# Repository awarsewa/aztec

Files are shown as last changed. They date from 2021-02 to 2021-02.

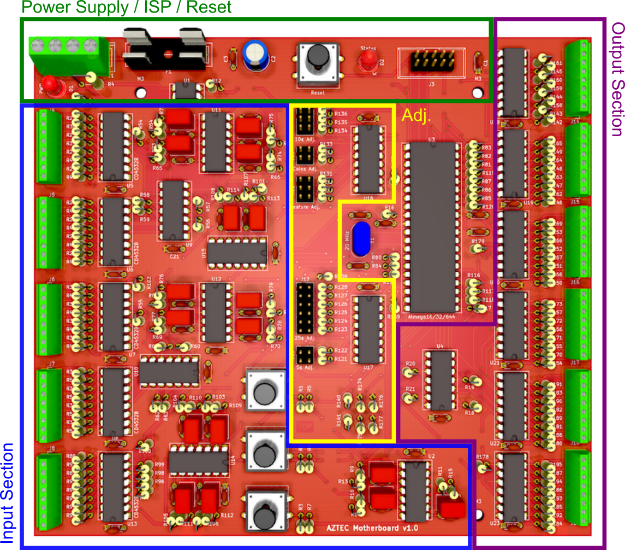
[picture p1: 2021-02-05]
docs/images/aztec_pcb_rendering.png

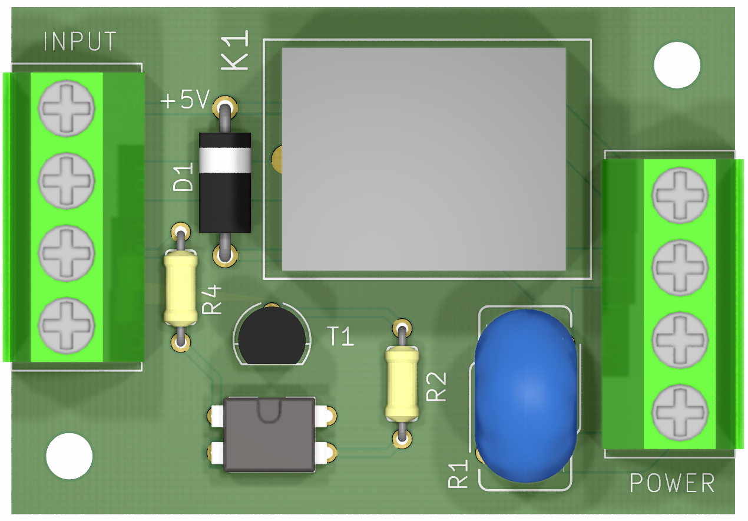
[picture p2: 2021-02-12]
docs/images/relay_pcb.png

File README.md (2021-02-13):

# aztec
Bringing a 1976 pinball machine back to life.

[:corn: Wiki](https://github.com/awarsewa/aztec/wiki)

### The machine
Aztec is a Williams® pinball machine for 4 players. Check it out on the [Internet Pinball Machine Database](https://www.ipdb.org/machine.cgi?gid=119). There is also a [solid state version](https://www.ipdb.org/machine.cgi?gid=4828) of the same machine. Mine is from the electromechanical series -- and this is where the fun starts. Of course it wasn't functional. The entire cabinet had been completely gutted, with only a few tilt mechanisms left dangling about. However, the playfield and the backbox were still mostly intact. Repairing it seemed tough, but since it's cool to have your own pinball machine, I decided to give it a shot.

### The project
It would have been rather expensive and difficult to get original spare parts for, or replicas of, all the missing components. So why not replace aztec's brain with a microcontroller? The looks and feel of the machine would still be the same. Only what's under the hood would be slightly more modern. Maybe this is a sacrilege for real pinball lovers... I have a feeling it is. Like an inverse Frankenstein - pretty on the outside. But I already did it, so there's no way back and no repentance. If you want to know how I've done it, check out the [:corn: repository wiki](https://github.com/awarsewa/aztec/wiki).

### What's in this repository?
The source code running on the microcontroller and the PCB schematics. Basically everything you need to do something similar. 

### Getting involved
In case you have questions or suggestions, need support or simply want to get in touch, feel free to [send me a message](mailto:alexander.warsewa@posteo.net?subject=[Aztec]).

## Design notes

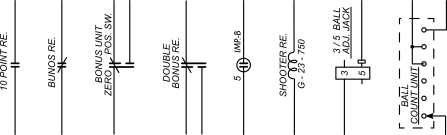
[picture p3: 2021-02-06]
docs/images/schematic_symbols.png

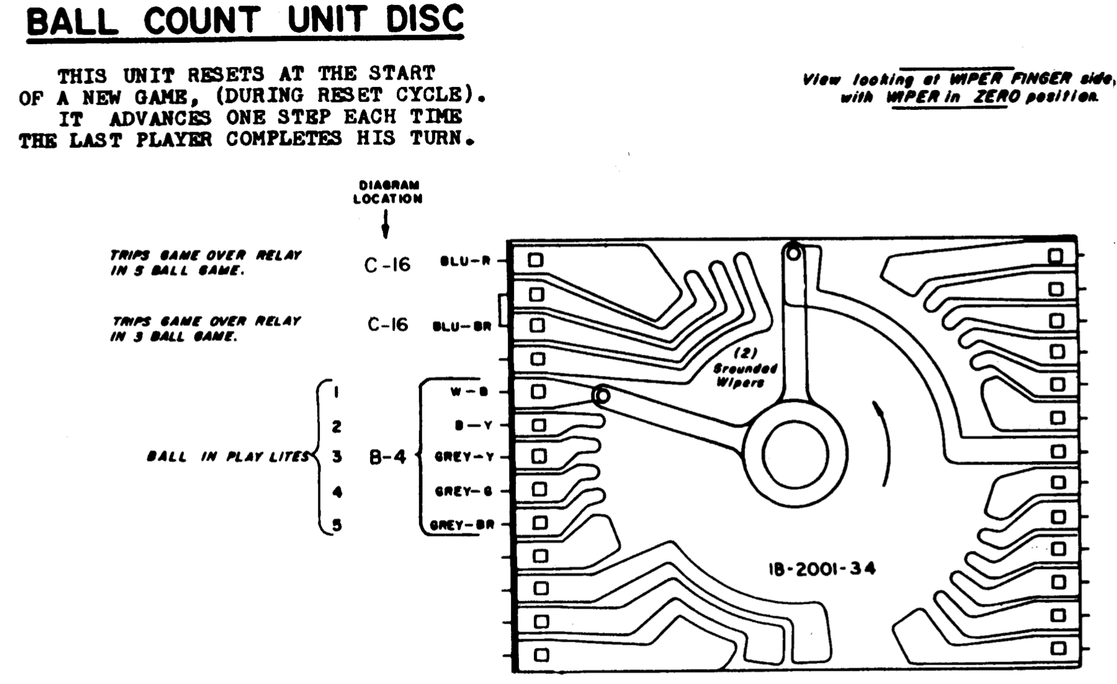
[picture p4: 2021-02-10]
docs/images/ball_count_unit.png

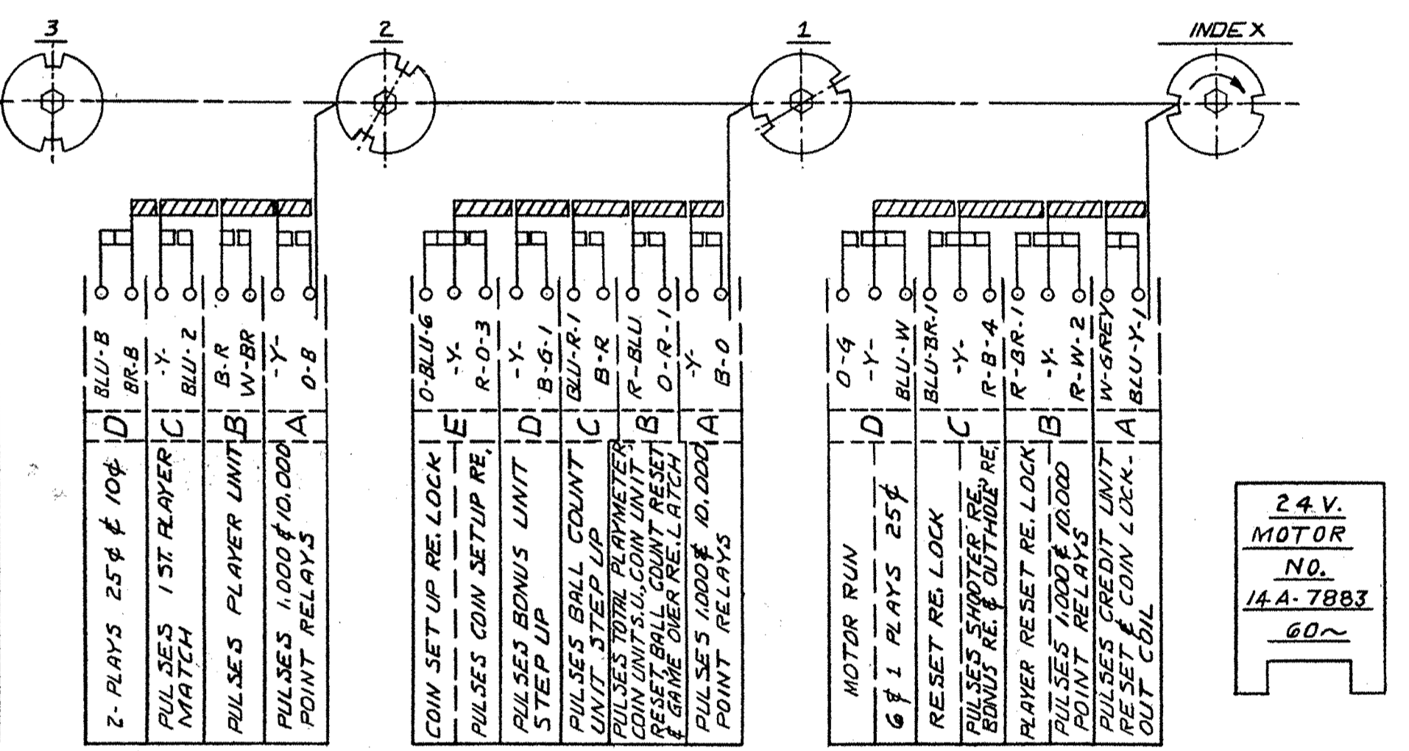
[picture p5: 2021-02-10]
docs/images/score_motor.png

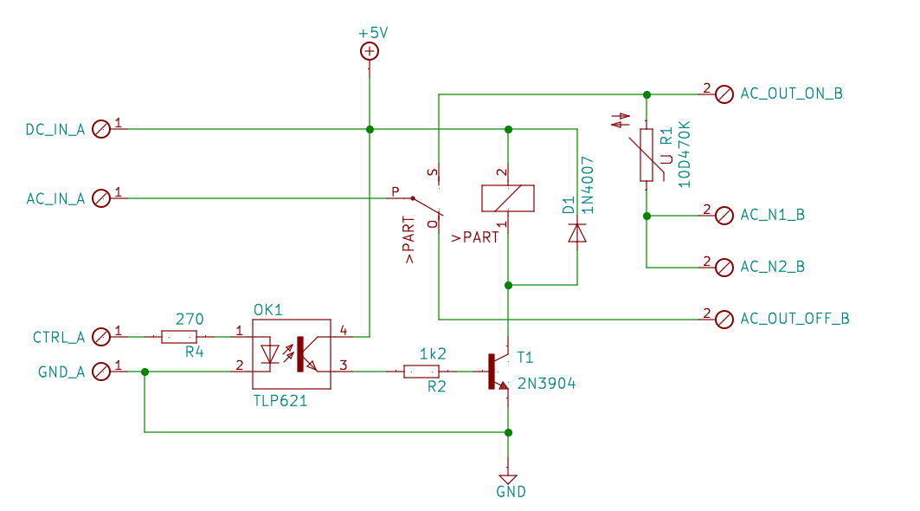
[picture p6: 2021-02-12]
docs/images/relay_sch.png

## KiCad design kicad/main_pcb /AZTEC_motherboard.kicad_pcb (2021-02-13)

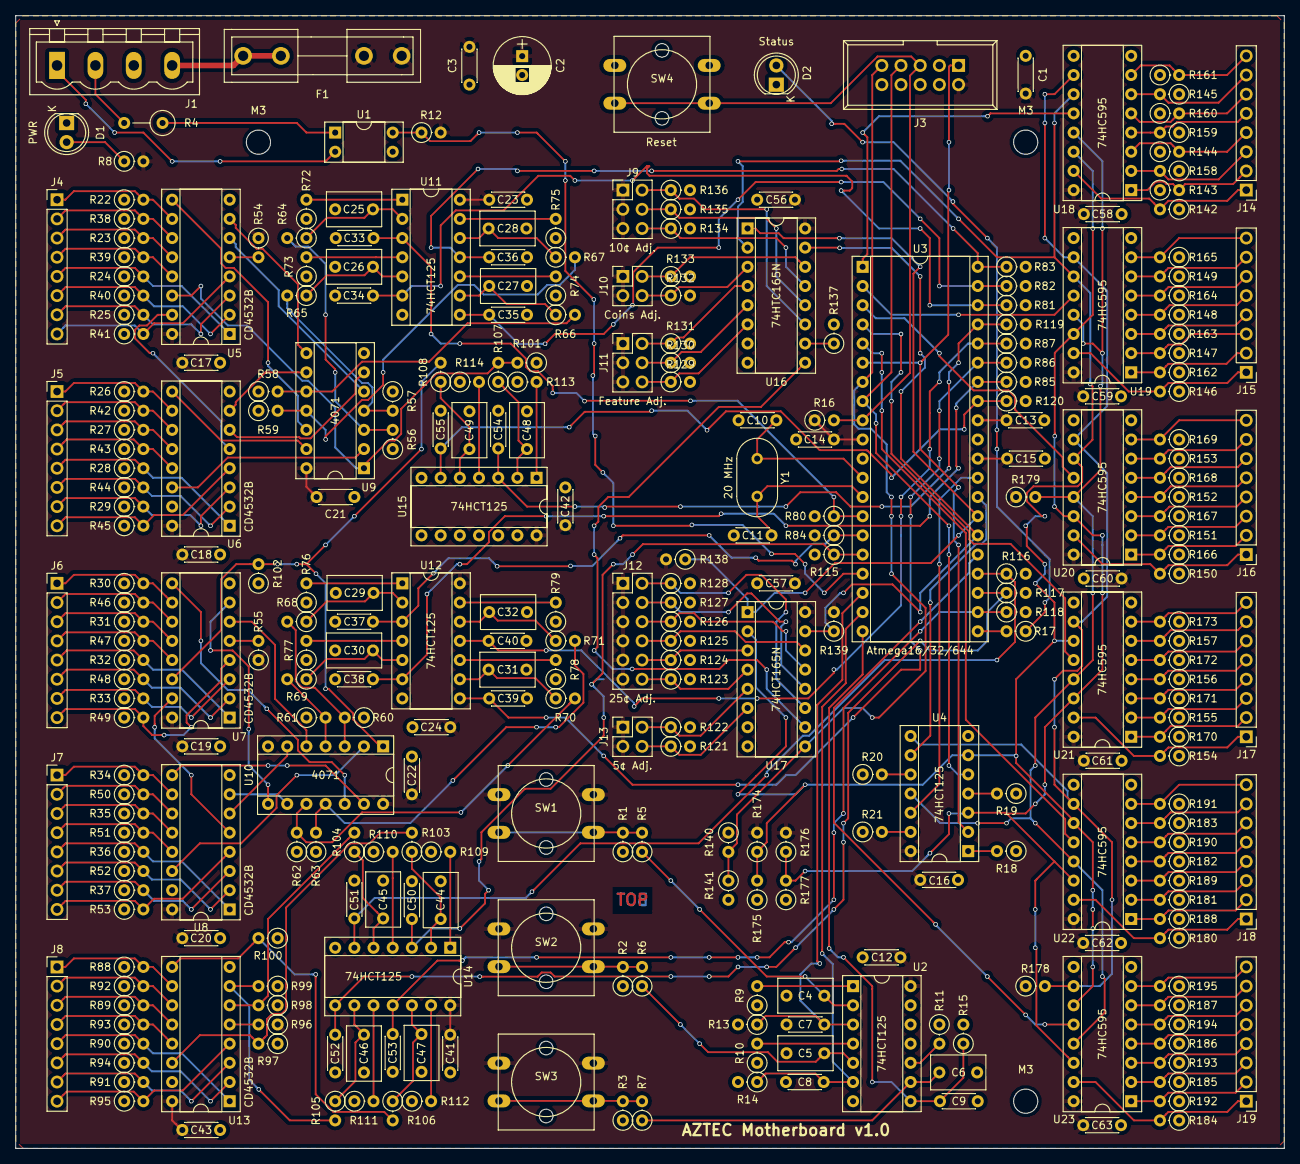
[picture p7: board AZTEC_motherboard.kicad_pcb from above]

Board: 2 copper layers, 168.0 x 150.0 mm, 310 parts (0 on the bottom side), 227 nets.

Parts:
C1, C3, C7, C8, C9, C12, C13, C14, C15, C16, C17, C18, C19, C20, C21, C22, C23, C24, C33, C34, C35, C36, C37, C38, C39, C40, C41, C42, C43, C50, C51, C52, C53, C54, C55, C56, C57, C58, C59, C60, C61, C62, C63: 100n; C_Disc_D4.3mm_W1.9mm_P5.00mm
C2: 1u; CP_Radial_D7.5mm_P2.50mm
C4, C5, C6, C25, C26, C27, C28, C29, C30, C31, C32, C44, C45, C46, C47, C48, C49: 1µ; C_Rect_L7.2mm_W4.5mm_P5.00mm_FKS2_FKP2_MKS2_MKP2
C10, C11: 22p; C_Disc_D4.3mm_W1.9mm_P5.00mm
D1: PWR; LED-5MM
D2: STATUS; LED-5MM
F1: Fuse; Fuseholder5x20_horiz_open_inline_Type-I
J1: Conn_01x04_Female; PhoenixContact_MSTBVA-G_04x5.08mm_Vertical
J3: ISP; IDC_Header_Straight_10pins
J4: Inputs_1; Pin_Header_Straight_1x08_Pitch2.54mm
J5: Inputs_2; Pin_Header_Straight_1x08_Pitch2.54mm
J6: Inputs_3; Pin_Header_Straight_1x08_Pitch2.54mm
J7: Inputs_4; Pin_Header_Straight_1x08_Pitch2.54mm
J8: Inputs_5; Pin_Header_Straight_1x08_Pitch2.54mm
J9: 10¢ Adjust; Pin_Header_Straight_2x03_Pitch2.54mm
J10: 2 coins - 3 plays; Pin_Header_Straight_2x02_Pitch2.54mm
J11: Feature Adjust; Pin_Header_Straight_2x03_Pitch2.54mm
J12: 25¢ Adjust; Pin_Header_Straight_2x06_Pitch2.54mm
J13: 5¢ Adjust; Pin_Header_Straight_2x02_Pitch2.54mm
J14: Outputs_1; Pin_Header_Straight_1x08_Pitch2.54mm
J15: Outputs_2; Pin_Header_Straight_1x08_Pitch2.54mm
J16: Outputs_3; Pin_Header_Straight_1x08_Pitch2.54mm
J17: Outputs_4; Pin_Header_Straight_1x08_Pitch2.54mm
J18: Outputs_5; Pin_Header_Straight_1x08_Pitch2.54mm
J19: Outputs_6; Pin_Header_Straight_1x08_Pitch2.54mm
M3, M3#2, M3#3: MountingHole_3.2mm_M3
R1, R2, R3, R9, R10, R11, R12, R13, R14, R15, R16, R18, R19, R20, R21, R22, R23, R24, R25, R26, R27, R28, R29, R30, R31, R32, R33, R34, R35, R36, R37, R38, R39, R40, R41, R42, R43, R44, R45, R46, R47, R48, R49, R50, R51, R52, R53, R54, R55, R56, R57, R58, R59, R60, R61, R62, R63, R72, R73, R74, R75, R76, R77, R78, R79, R80, R81, R82, R83, R84, R85, R86, R87, R88, R89, R90, R91, R92, R93, R94, R95, R96, R97, R98, R99, R100, R101, R102, R109, R110, R111, R112, R113, R114, R115, R116, R117, R118, R119, R120, R121, R122, R123, R124, R125, R126, R127, R128, R129, R130, R131, R132, R133, R134, R135, R136, R137, R138, R139, R140, R141, R142, R143, R144, R145, R146, R147, R148, R149, R150, R151, R152, R153, R154, R155, R156, R157, R158, R159, R160, R161, R162, R163, R164, R165, R166, R167, R168, R169, R170, R171, R172, R173, R174, R175, R176, R177, R178, R179, R180, R181, R182, R183, R184, R185, R186, R187, R188, R189, R190, R191, R192, R193, R194, R195: 10k; R_Axial_DIN0207_L6.3mm_D2.5mm_P2.54mm_Vertical
R4: 2k2; R_Axial_DIN0309_L9.0mm_D3.2mm_P5.08mm_Vertical
R5, R6, R7, R64, R65, R66, R67, R68, R69, R70, R71, R103, R104, R105, R106, R107, R108: 22k; R_Axial_DIN0207_L6.3mm_D2.5mm_P2.54mm_Vertical
R8, R17: 100R; R_Axial_DIN0207_L6.3mm_D2.5mm_P2.54mm_Vertical
SW1, SW2, SW3, SW4: Reset; SW_PUSH-AZTEC
U1: SFH620A; DIP-4_W7.62mm_Socket
U2, U4, U11, U12, U14, U15: 74HCT125; DIP-14_W7.62mm_Socket
U3: ATMEGA16/32/644; DIP-40_W15.24mm_Socket
U5, U6, U7, U8, U13: CD4532B; DIP-16_W7.62mm_Socket
U9, U10: 4071; DIP-14_W7.62mm_Socket
U16, U17: 74HCT165N; DIP-16_W7.62mm_Socket
U18, U19, U20, U21, U22, U23: 74HC595; DIP-16_W7.62mm_Socket
Y1: 20 MHz; Resonator-2pin_w10.0mm_h5.0mm

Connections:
/AC_zero_crossing: R12.1, U1.4, U3.17
/Adjusts/CP: R174.1, R175.2, U4.6, U16.2, U17.2, U18.11, U19.11, U20.11, U21.11, U22.11, U23.11
/Adjusts/~CE: R139.1, U3.26, U16.15, U17.15
/Adjusts/~PL: R138.1, U3.27, U16.1, U17.1
/Button1: C7.2, R13.1, U2.3, U3.18
/Button2: C8.2, R14.1, U2.6, U3.19
/Button3: C9.2, R15.1, U2.8, U3.20
/Inputs/GS1: C33.2, R80.1, U3.14, U11.3
/Inputs/GS2: C37.2, R84.1, U3.15, U12.3
/Inputs/GS3: C50.2, R115.1, U3.16, U14.3
/Inputs/Q10: C36.2, R83.1, U3.40, U11.11
/Inputs/Q11: C35.2, R82.1, U3.39, U11.8
/Inputs/Q12: C34.2, R81.1, U3.38, U11.6
/Inputs/Q13: C54.2, R119.1, U3.37, U15.3
/Inputs/Q20: C40.2, R87.1, U3.36, U12.11
/Inputs/Q21: C39.2, R86.1, U3.35, U12.8
/Inputs/Q22: C38.2, R85.1, U3.34, U12.6
/Inputs/Q23: C55.2, R120.1, U3.33, U15.6
/Inputs/Q30: C53.2, R118.1, U3.22, U14.11
/Inputs/Q31: C52.2, R117.1, U3.23, U14.8
/Inputs/Q32: C51.2, R116.1, U3.24, U14.6
/MISO: J3.9, R140.2, R141.1, U3.7, U17.9
/MOSI: J3.1, U3.6, U4.2
/Outputs/MOSI_buf: R176.1, R177.2, U4.3, U18.14, U19.14, U20.14, U21.14, U22.14, U23.14
/Outputs/RCK1: U3.1, U18.12
/Outputs/RCK2: U3.2, U19.12
/Outputs/RCK3: U3.3, U20.12
/Outputs/RCK4: U3.4, U21.12
/Outputs/RCK5: U3.5, U22.12
/Outputs/RCK6: U3.25, U23.12
/Outputs/~OE_buf: R179.2, U4.11, U18.13, U19.13, U20.13, U21.13, U22.13, U23.13
/Outputs/~SCL_buf: R178.2, U4.8, U18.10, U19.10, U20.10, U21.10, U22.10, U23.10
/SCK: J3.7, U3.8, U4.5
/~OE: U3.29, U4.12
/~RESET: J3.5, R16.2, SW4.2, SW4.4, U3.9
/~SCL: U3.28, U4.9
GND: C1.1, C2.2, C3.1, C4.1, C5.1, C6.1, C7.1, C8.1, C9.1, C10.2, C11.2, C12.2, C13.1, C14.1, C15.2, C16.2, C17.1, C18.1, C19.1, C20.1, C21.1, C22.1, C23.2, C24.2, C25.1, C26.1, C27.1, C28.1, C29.1, C30.1, C31.1, C32.1, C33.1, C34.1, C35.1, C36.1, C37.1, C38.1, C39.1, C40.1, C41.2, C42.2, C43.1, C44.1, C45.1, C46.1, C47.1, C48.1, C49.1, C50.1, C51.1, C52.1, C53.1, C54.1, C55.1, C56.1, C57.1, C58.2, C59.2, C60.2, C61.2, C62.2, C63.2, D1.1, D2.1, J1.3, J3.4, J3.6, J3.8, J3.10, R1.1, R2.1, R3.1, R9.1, R10.1, R11.1, R13.2, R14.2, R15.2, R18.1, R19.1, R20.1, R21.1, R22.1, R23.1, R24.1, R25.1, R26.1, R27.1, R28.1, R29.1, R30.1, R31.1, R32.1, R33.1, R34.1, R35.1, R36.1, R37.1, R38.1, R39.1, R40.1, R41.1, R42.1, R43.1, R44.1, R45.1, R46.1, R47.1, R48.1, R49.1, R50.1, R51.1, R52.1, R53.1, R56.1, R57.1, R58.1, R59.1, R60.1, R61.1, R62.1, R63.1, R72.1, R73.1, R74.1, R75.1, R76.1, R77.1, R78.1, R79.1, R80.2, R81.2, R82.2, R83.2, R84.2, R85.2, R86.2, R87.2, R88.1, R89.1, R90.1, R91.1, R92.1, R93.1, R94.1, R95.1, R97.1, R98.1, R99.1, R100.1, R101.1, R102.1, R109.1, R110.1, R111.1, R112.1, R113.1, R114.1, R115.2, R116.2, R117.2, R118.2, R119.2, R120.2, R121.2, R122.2, R123.2, R124.2, R125.2, R126.2, R127.2, R128.2, R129.2, R130.2, R131.2, R132.2, R133.2, R134.2, R135.2, R136.2, R137.2, R141.2, R142.1, R143.1, R144.1, R145.1, R146.1, R147.1, R148.1, R149.1, R150.1, R151.1, R152.1, R153.1, R154.1, R155.1, R156.1, R157.1, R158.1, R159.1, R160.1, R161.1, R162.1, R163.1, R164.1, R165.1, R166.1, R167.1, R168.1, R169.1, R170.1, R171.1, R172.1, R173.1, R175.1, R177.1, R180.1, R181.1, R182.1, R183.1, R184.1, R185.1, R186.1, R187.1, R188.1, R189.1, R190.1, R191.1, R192.1, R193.1, R194.1, R195.1, SW4.1, SW4.3, U1.3, U2.7, U3.11, U3.31, U4.7, U5.8, U6.8, U7.8, U8.8, U9.7, U10.7, U11.7, U12.7, U13.8, U14.7, U15.7, U16.8, U17.8, U18.8, U19.8, U20.8, U21.8, U22.8, U23.8
unnamed: C4.2, R5.1, U2.2
unnamed: C5.2, R6.1, U2.5
unnamed: C6.2, R7.1, U2.9
unnamed: C10.1, U3.12, Y1.1
unnamed: C11.1, U3.13, Y1.2
unnamed: C25.2, R64.1, U11.2
unnamed: C26.2, R65.1, U11.5
unnamed: C27.2, R66.1, U11.9
unnamed: C28.2, R67.1, U11.12
unnamed: C29.2, R68.1, U12.2
unnamed: C30.2, R69.1, U12.5
unnamed: C31.2, R70.1, U12.9
unnamed: C32.2, R71.1, U12.12
unnamed: C44.2, R103.1, U14.2
unnamed: C45.2, R104.1, U14.5
unnamed: C46.2, R105.1, U14.9
unnamed: C47.2, R106.1, U14.12
unnamed: C48.2, R107.1, U15.2
unnamed: C49.2, R108.1, U15.5
unnamed: D1.2, R8.1
unnamed: D2.2, R17.1
unnamed: F1.2, J1.4
unnamed: J1.1, U1.2
unnamed: J1.2, R4.2
unnamed: J4.1, R22.2, U5.10
unnamed: J4.2, R38.2, U5.11
unnamed: J4.3, R23.2, U5.12
unnamed: J4.4, R39.2, U5.13
unnamed: J4.5, R24.2, U5.1
unnamed: J4.6, R40.2, U5.2
unnamed: J4.7, R25.2, U5.3
unnamed: J4.8, R41.2, U5.4
unnamed: J5.1, R26.2, U6.10
unnamed: J5.2, R42.2, U6.11
unnamed: J5.3, R27.2, U6.12
unnamed: J5.4, R43.2, U6.13
unnamed: J5.5, R28.2, U6.1
unnamed: J5.6, R44.2, U6.2
unnamed: J5.7, R29.2, U6.3
unnamed: J5.8, R45.2, U6.4
unnamed: J6.1, R30.2, U7.10
unnamed: J6.2, R46.2, U7.11
unnamed: J6.3, R31.2, U7.12
unnamed: J6.4, R47.2, U7.13
unnamed: J6.5, R32.2, U7.1
unnamed: J6.6, R48.2, U7.2
unnamed: J6.7, R33.2, U7.3
unnamed: J6.8, R49.2, U7.4
unnamed: J7.1, R34.2, U8.10
unnamed: J7.2, R50.2, U8.11
unnamed: J7.3, R35.2, U8.12
unnamed: J7.4, R51.2, U8.13
unnamed: J7.5, R36.2, U8.1
unnamed: J7.6, R52.2, U8.2
unnamed: J7.7, R37.2, U8.3
unnamed: J7.8, R53.2, U8.4
unnamed: J8.1, R88.2, U13.10
unnamed: J8.2, R92.2, U13.11
unnamed: J8.3, R89.2, U13.12
unnamed: J8.4, R93.2, U13.13
unnamed: J8.5, R90.2, U13.1
unnamed: J8.6, R94.2, U13.2
unnamed: J8.7, R91.2, U13.3
unnamed: J8.8, R95.2, U13.4
unnamed: J9.2, R136.1, U16.11
unnamed: J9.4, R135.1, U16.12
unnamed: J9.6, R134.1, U16.13
unnamed: J10.2, R133.1, U16.14
unnamed: J10.4, R132.1, U16.3
unnamed: J11.2, R131.1, U16.4
unnamed: J11.4, R130.1, U16.5
unnamed: J11.6, R129.1, U16.6
unnamed: J12.2, R128.1, U17.11
unnamed: J12.4, R127.1, U17.12
unnamed: J12.6, R126.1, U17.13
unnamed: J12.8, R125.1, U17.14
unnamed: J12.10, R124.1, U17.3
unnamed: J12.12, R123.1, U17.4
unnamed: J13.2, R122.1, U17.5
unnamed: J13.4, R121.1, U17.6
unnamed: J14.1, R142.2, U18.15
unnamed: J14.2, R158.2, U18.1
unnamed: J14.3, R143.2, U18.2
unnamed: J14.4, R159.2, U18.3
unnamed: J14.5, R144.2, U18.4
unnamed: J14.6, R160.2, U18.5
unnamed: J14.7, R145.2, U18.6
unnamed: J14.8, R161.2, U18.7
unnamed: J15.1, R146.2, U19.15
unnamed: J15.2, R162.2, U19.1
unnamed: J15.3, R147.2, U19.2
unnamed: J15.4, R163.2, U19.3
unnamed: J15.5, R148.2, U19.4
unnamed: J15.6, R164.2, U19.5
unnamed: J15.7, R149.2, U19.6
unnamed: J15.8, R165.2, U19.7
unnamed: J16.1, R150.2, U20.15
unnamed: J16.2, R166.2, U20.1
unnamed: J16.3, R151.2, U20.2
unnamed: J16.4, R167.2, U20.3
unnamed: J16.5, R152.2, U20.4
unnamed: J16.6, R168.2, U20.5
unnamed: J16.7, R153.2, U20.6
unnamed: J16.8, R169.2, U20.7
unnamed: J17.1, R154.2, U21.15
unnamed: J17.2, R170.2, U21.1
unnamed: J17.3, R155.2, U21.2
unnamed: J17.4, R171.2, U21.3
unnamed: J17.5, R156.2, U21.4
unnamed: J17.6, R172.2, U21.5
unnamed: J17.7, R157.2, U21.6
unnamed: J17.8, R173.2, U21.7
unnamed: J18.1, R180.2, U22.15
unnamed: J18.2, R188.2, U22.1
unnamed: J18.3, R181.2, U22.2
unnamed: J18.4, R189.2, U22.3
unnamed: J18.5, R182.2, U22.4
unnamed: J18.6, R190.2, U22.5
unnamed: J18.7, R183.2, U22.6
unnamed: J18.8, R191.2, U22.7
unnamed: J19.1, R184.2, U23.15
unnamed: J19.2, R192.2, U23.1
unnamed: J19.3, R185.2, U23.2
unnamed: J19.4, R193.2, U23.3
unnamed: J19.5, R186.2, U23.4
unnamed: J19.6, R194.2, U23.5
unnamed: J19.7, R187.2, U23.6
unnamed: J19.8, R195.2, U23.7
unnamed: R1.2, R5.2, SW1.2, SW1.4
unnamed: R2.2, R6.2, SW2.2, SW2.4
unnamed: R3.2, R7.2, SW3.2, SW3.4
unnamed: R4.1, U1.1
unnamed: R9.2, U2.1
unnamed: R10.2, U2.4
unnamed: R11.2, U2.10
unnamed: R17.2, U3.21
unnamed: R18.2, U4.1
unnamed: R19.2, U4.4
unnamed: R20.2, U4.10
unnamed: R21.2, U4.13
unnamed: R54.2, U5.5
unnamed: R55.2, U7.5
unnamed: R56.2, R64.2, U9.3
unnamed: R57.2, R65.2, U9.4
unnamed: R58.2, R66.2, U9.10
unnamed: R59.2, R67.2, U9.11
unnamed: R60.2, R68.2, U10.3
unnamed: R61.2, R69.2, U10.4
unnamed: R62.2, R70.2, U10.10
unnamed: R63.2, R71.2, U10.11
unnamed: R72.2, U11.1
unnamed: R73.2, U11.4
unnamed: R74.2, U11.10
unnamed: R75.2, U11.13
unnamed: R76.2, U12.1
unnamed: R77.2, U12.4
unnamed: R78.2, U12.10
unnamed: R79.2, U12.13
unnamed: R96.2, U13.5
unnamed: R100.2, R106.2, U13.9
unnamed: R101.2, R107.2, U5.14, U9.1
unnamed: R102.2, R108.2, U7.14, U10.1
unnamed: R97.2, R103.2, U13.14
unnamed: R98.2, R104.2, U13.6
unnamed: R99.2, R105.2, U13.7
unnamed: R109.2, U14.1
unnamed: R110.2, U14.4
unnamed: R111.2, U14.10
unnamed: R112.2, U14.13
unnamed: R113.2, U15.1
unnamed: R114.2, U15.4
unnamed: R137.1, U16.10
unnamed: U5.6, U9.5
unnamed: U5.7, U9.8
unnamed: U5.9, U9.12
unnamed: U5.15, U6.5
unnamed: U6.6, U9.6
unnamed: U6.7, U9.9
unnamed: U6.9, U9.13
unnamed: U6.14, U9.2
unnamed: U7.15, U8.5
unnamed: U8.14, U10.2
unnamed: U7.6, U10.5
unnamed: U8.6, U10.6
unnamed: U7.7, U10.8
unnamed: U8.7, U10.9
unnamed: U7.9, U10.12
unnamed: U8.9, U10.13
unnamed: U16.9, U17.10
VCC: C1.2, C2.1, C3.2, C12.1, C13.2, C14.2, C15.1, C16.1, C17.2, C18.2, C19.2, C20.2, C21.2, C22.2, C23.1, C24.1, C41.1, C42.1, C43.2, C56.2, C57.2, C58.1, C59.1, C60.1, C61.1, C62.1, C63.1, F1.1, J3.2, J9.1, J9.3, J9.5, J10.1, J10.3, J11.1, J11.3, J11.5, J12.1, J12.3, J12.5, J12.7, J12.9, J12.11, J13.1, J13.3, R8.2, R12.2, R16.1, R54.1, R55.1, R96.1, R138.2, R139.2, R140.1, R174.2, R176.2, R178.1, R179.1, SW1.1, SW1.3, SW2.1, SW2.3, SW3.1, SW3.3, U2.14, U3.10, U3.30, U3.32, U4.14, U5.16, U6.16, U7.16, U8.16, U9.14, U10.14, U11.14, U12.14, U13.16, U14.14, U15.14, U16.16, U17.16, U18.16, U19.16, U20.16, U21.16, U22.16, U23.16

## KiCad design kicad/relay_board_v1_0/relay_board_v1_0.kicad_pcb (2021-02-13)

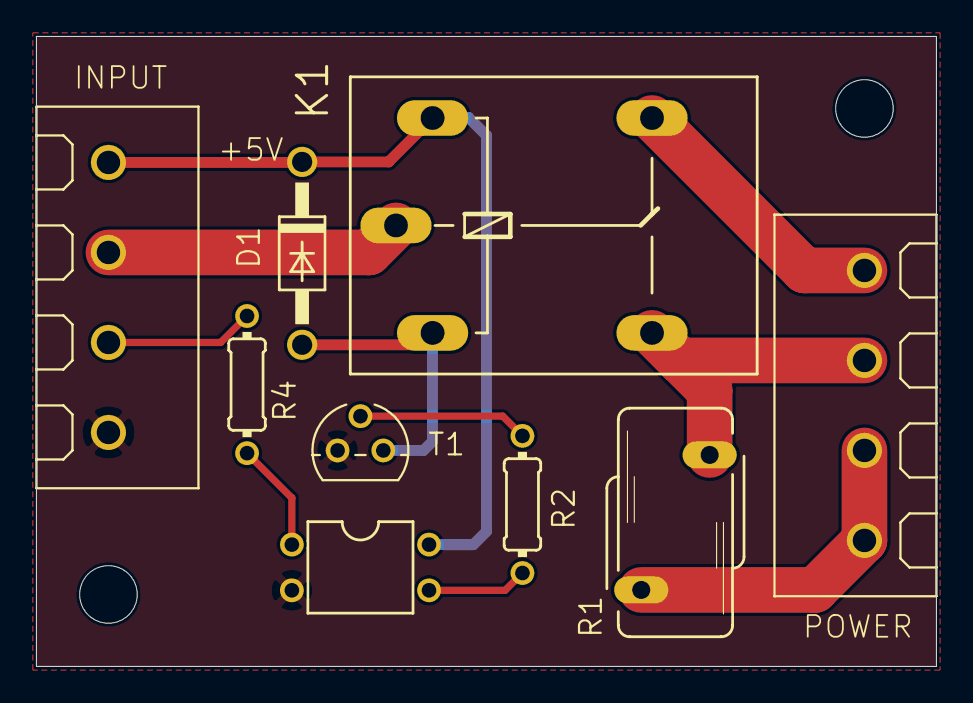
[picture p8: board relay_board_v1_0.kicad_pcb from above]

Board: 2 copper layers, 50.0 x 35.0 mm, 11 parts (0 on the bottom side), 11 nets.

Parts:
@HOLE0, @HOLE1: (no value)
D1: 1N4007; DO41-10
INPUT: OSTTA040161; 040161
K1: G5LE
OK1: TLP621; DIL04
POWER: OSTTA040161; 040161
R1: 10D470K
R2: 1k2; 0204_7
R4: 270; 0204_7
T1: 2N3904; TO92

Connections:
+5V: D1.C, INPUT.1, K1.2, OK1.4
GND: INPUT.4, OK1.2, T1.3
unnamed: D1.A, K1.1, T1.1
unnamed: INPUT.2, K1.P
unnamed: INPUT.3, R4.2
unnamed: K1.O, POWER.4
unnamed: K1.S, POWER.3, R1.2
unnamed: OK1.1, R4.1
unnamed: OK1.3, R2.2
unnamed: POWER.1, POWER.2, R1.1
unnamed: R2.1, T1.2

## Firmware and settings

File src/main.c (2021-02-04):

/* Name: main.c
 * Author: Alex
 * Copyright: 2016 by Alexander Warsewa
 * License:
 */

#include <avr/io.h>
#include <avr/wdt.h>
#include <avr/interrupt.h>
#include <util/delay.h>
#include <util/atomic.h>
#include "SPI.h"
#include "AZTEC_relays.h"
#include "score_motor.h"
#include "ball_count_unit.h"
#include "player_unit.h"
#include "credit_unit.h"
#include "coin_unit.h"
#include "bonus_unit.h"
#include "queue.h"

#define enableZeroCrossInt()    GIFR |= (1 << INTF0); GICR |= (1 << INT0)
#define disableZeroCrossInt()   GICR &= ~(1 << INT0)
#define zeroCrossIntActive()    (GICR & (1 << INT0))

#define isBitSet(bit, reg)      ((1 << (bit)) & reg)
#define setBit(bit, reg)        reg |= (1 << (bit))
#define clearBit(bit, reg)      reg &= ~(1 << (bit))

#define isActive(src)           (AZTEC_EVENT_PIN & src)

/*
#define SWITCH_INFO_DEPTH       60

struct swInfo
{
    struct mb* on;
    struct mb* off;
    uint8_t    n_on;
    uint8_t    n_off;
    uint8_t    traceFlag;
};

struct swInfo switchInfo[SWITCH_INFO_DEPTH];
queue  swInfoQueue;
*/

//TODO: check zero crossing interrupt with oscilloscope

/*
 * AC zero crossing interrupt
 * Used for switching off inductive loads
 * Interrupt is enabled when a coil is to be switched off
 * Corresponding register is then latched (with the coil's output set to low before)
 * When called, interrupt is disabled right away to not generate too much overload
 */
/*
ISR(INT0_vect)
{
    ATOMIC_BLOCK(ATOMIC_FORCEON){
        // write data to register
        shiftReg_write(latchSR);
        // latch selected register
        shiftReg_store(latchSR);
        
        // disable interrupt
        disableZeroCrossInt();
    }
}*/

ISR(TIMER2_OVF_vect)
{
    static uint8_t statCount;
    
    ATOMIC_BLOCK(ATOMIC_FORCEON){
        if(++statCount == 30){
            PORTD ^= (1 << PD7);
            statCount = 0;
        }
    }
}

void init_hardware(void)
{
    // Set all pins of input port to tri-state inputs
    AZTEC_INPUT_DDR = 0x00;
    AZTEC_INPUT_PORT = 0x00;
    
    AZTEC_OUTPUT_DDR = (1 << AZTEC_SPI_RCK1) | (1 << AZTEC_SPI_RCK2) | (1 << AZTEC_SPI_RCK3) | \
    (1 << AZTEC_SPI_RCK4) | ( 1 << AZTEC_SPI_RCK5) | (1 << AZTEC_SPI_MOSI) | \
    (1 << AZTEC_SPI_SCK);
    AZTEC_OUTPUT_PORT = 0x00;
    
    
    AZTEC_CONTROL_DDR = (1 << AZTEC_OUTPUT_ENABLE) | (1 << AZTEC_CLOCK_ENABLE) | (1 << AZTEC_PARALLEL_LOAD) | (1 << AZTEC_SERIAL_CLEAR);
    AZTEC_CONTROL_PORT = (1 << AZTEC_OUTPUT_ENABLE) | (1 << AZTEC_CLOCK_ENABLE) | (1 << AZTEC_PARALLEL_LOAD) | (1 << AZTEC_SERIAL_CLEAR);
    
    // Set all pins of event port to function as inputs (tri-state)
    AZTEC_EVENT_DDR = 0x00;
    AZTEC_EVENT_PORT = 0x00;
    
    // Auxiliary inputs are on control port
    
    // Set INT0 and INT1 to trigger on rising edge
    MCUCR = (1 << ISC01) | (1 << ISC00) | (1 << ISC11) | (1 << ISC10);
    
    
    // TODO: init SPI
    SPCR = (1 << SPE) | (1 << MSTR) | (0 << CPOL) | (0 <<  CPHA);
    // enable fast mode
    SPSR = (1 << SPI2X);
    
    // Init relay.c (init queue)
    relay_init();

    outRegs[0].storePin = (1 << AZTEC_SPI_RCK1);
    outRegs[1].storePin = (1 << AZTEC_SPI_RCK2);
    outRegs[2].storePin = (1 << AZTEC_SPI_RCK3);
    outRegs[3].storePin = (1 << AZTEC_SPI_RCK4);
    outRegs[4].storePin = (1 << AZTEC_SPI_RCK5);
    
    // clear shift registers
    AZTEC_CONTROL_PORT &= ~(1 << AZTEC_SERIAL_CLEAR);
    _delay_ms(1);
    AZTEC_CONTROL_PORT |=  (1 << AZTEC_SERIAL_CLEAR);
    
    
    DDRD |= (1 << PD7);
    // Enable Timer2 for toggling the status LED
    TCCR2B = (1 << CS20) | (1 << CS21) | (1 << CS22);
    TIMSK2 = (1 << TOIE2);
    
    //set motor speed to ~32 rpm
    OCR1A = MOTOR_STEP_TIME;
	TCCR1A = 0x00;
    TIFR1 |= (1 << OCF1A); TIMSK1 |= (1 << OCIE1A);
}

void aztec_init(void)
{
    // Init to state before game over (5 balls in play)
    ballCountUnitDiskPos = BALL_COUNT_UNIT_DISK_POS_5;
    switchOff(toSwitchPtr(&sw_ballCountUnitZeroBk));
    switchOff(toSwitchPtr(&sw_ballCountUnitZeroBk2));
    // Trigger ball count unit step up to induce game over
    switchOn(toSwitchPtr(&relay_ballCountUnitStepUp));
    _delay_ms(50);
    switchOff(toSwitchPtr(&relay_ballCountUnitStepUp));
    
    // TODO:
    // read the adjust switch settings
    
    // setup connections of sw_5ct, sw_10ctm ... accordingly
    // including score motor CAMs (see A2 in the schematic)
    
    // read in credit unit state a.s.o from auxiliary input (nr. 5)
    
}

void processEvent(uint8_t src, uint8_t event, uint8_t flank)
{
    struct mb* sw = NULL;
    
    switch(src){
       case AZTEC_EVENT_SRC_GS1:
            switch(event){
                case L_LANE_ROLL_OVER:
                    if(flank)
                        switchOn(toSwitchPtr(&sw_leftLaneRollOver));
                    else
                        switchOff(toSwitchPtr(&sw_leftLaneRollOver));
                    sw = toSwitchPtr(&sw_leftLaneRollOver2);
                    break;
                case E_TARGET:
                    sw = toSwitchPtr(&sw_targetE);
                    break;
                case Z_TARGET:
                    sw = toSwitchPtr(&sw_targetZ);
                    break;
                case CENTER_JET_BUMPER:
                    sw = toSwitchPtr(&sw_centerJetBumper);
                    break;
                case R_JET_BUMPER:
                    sw = toSwitchPtr(&sw_rightJetBumper);
                    break;
                case L_JET_BUMPER:
                    sw = toSwitchPtr(&sw_leftJetBumper);
                    break;
                case CENTER_TOP_ROLL_OVER:
                    sw = toSwitchPtr(&sw_centerTopRollOver);
                    break;
                case R_TOP_ROLL_OVER:
                    sw = toSwitchPtr(&sw_rightTopRollOver);
                    break;
                case L_TOP_ROLL_OVER:
                    sw = toSwitchPtr(&sw_leftTopRollOver);
                    break;
                case CENTER_TARGET:
                    sw = toSwitchPtr(&sw_centerTarget);
                    break;
                case L_TOP_TARGET:
                    sw = toSwitchPtr(&sw_leftTopTarget);
                    break;
                case L_BOT_ROLL_OVER_IN:
                    sw = toSwitchPtr(&sw_leftBottomRollOverIn);
                    break;
                case L_BOT_ROLL_OVER_OUT:
                    sw = toSwitchPtr(&sw_leftBottomRollOverOut);
                    break;
                case L_R_TOP_ROLL_OVER_BUTTON:
                    sw = toSwitchPtr(&sw_leftRightTopRollOverButton);
                    break;
                case CENTER_TOP_ROLL_OVER_BUTTON:
                    sw = toSwitchPtr(&sw_centerTopRollOverButton);
                    break;
                case SPINNER:
                    sw = toSwitchPtr(&sw_spinner);
                    break;
                default:
                    break;
            }
            break;
        case AZTEC_EVENT_SRC_GS2:
            switch(event){
                case SHOOTER_SWITCH:
                    sw = toSwitchPtr(&sw_shooter);
                    _delay_ms(150);
                    break;
                case OUTHOLE_SWITCH:
                    sw = toSwitchPtr(&sw_outhole);
                    break;
                case CREDIT_BUTTON:
                    sw = toSwitchPtr(&sw_creditButton);
                    //sw = toSwitchPtr(&relay_ballRelease);
                    break;
                // When player scores 10 pts. no. match alternator switch triggers change re.
                case NUMBER_MATCH_S_U:
                    if(flank){
                        sw = toSwitchPtr(&sw_noMatchAlt);
                        if(sw_getState(toSwitchPtr(&sw_noMatchAlt)) == SWITCH_STATE_CLOSED)
                            flank = 0;
                        switchOn(toSwitchPtr(&relay_10Pt));
                        switchOff(toSwitchPtr(&relay_10Pt));
                    }
                    break;
                case C_TARGET:
                    sw = toSwitchPtr(&sw_targetC);
                    break;
                case T_TARGET:
                    sw = toSwitchPtr(&sw_targetT);
                    break;
                case R_BOT_ROLL_OVER_IN:
                    sw = toSwitchPtr(&sw_rightBottomRollOverIn);
                    break;
                case R_BOT_ROLL_OVER_OUT:
                    sw = toSwitchPtr(&sw_rightBottomRollOverOut);
                    break;
                /*
                case SWITCH_5_CT:
                    sw = toSwitchPtr(&sw_5ct);
                    break;
                case SWITCH_10_CT:
                    sw = toSwitchPtr(&sw_10ct);
                    break;
                case SWITCH_25_CT:
                    sw = toSwitchPtr(&sw_25ct);
                    break;
                */
                default:
                    break;
            }
            break;
        case AZTEC_EVENT_SRC_GS3:
            switch(event){
                case DRUM_UNIT_ZERO_BK_SWS:
                    sw = toSwitchPtr(&sw_drumUnitZeroBk);
                    flank = flank ? 0 : 1;
                    break;

                //case CREDIT_UNIT_ZERO_BK:
                //    sw = toSwitchPtr(&sw_creditUnitZeroBk);
                //    flank = flank ? 0 : 1;
                //    break;
                case CREDIT_UNIT_RESET_EOS:
                    sw = toSwitchPtr(&sw_creditUnitResetEOS);
                    break;
                default:
                    break;
            }
            break;
        // got 5¢
        case AZTEC_EVENT_SRC_BUT1:
            sw = toSwitchPtr(&sw_5ct);
            break;
        // got 10¢
        case AZTEC_EVENT_SRC_BUT2:
            sw = toSwitchPtr(&sw_10ct);
            break;
        // got 25¢
        case AZTEC_EVENT_SRC_BUT3:
            sw = toSwitchPtr(&sw_25ct);
            break;
        default:
            break;
    }
    if(sw != NULL){
        if(flank)
            switchOn(sw);
        else
            switchOff(sw);
    }
}

void sanityCheckGS1(uint8_t event)
{
    if(event != NO_EVENT)
        return;
    if(sw_getState(toSwitchPtr(&sw_centerTarget)) == SWITCH_STATE_CLOSED)
        switchOff(toSwitchPtr(&sw_centerTarget));
    if(sw_getState(toSwitchPtr(&sw_targetE)) == SWITCH_STATE_CLOSED)
        switchOff(toSwitchPtr(&sw_targetE));
    if(sw_getState(toSwitchPtr(&sw_targetZ)) == SWITCH_STATE_CLOSED)
        switchOff(toSwitchPtr(&sw_targetZ));
    if(sw_getState(toSwitchPtr(&sw_centerJetBumper)) == SWITCH_STATE_CLOSED)
        switchOff(toSwitchPtr(&sw_centerJetBumper));
    if(sw_getState(toSwitchPtr(&sw_rightJetBumper)) == SWITCH_STATE_CLOSED)
        switchOff(toSwitchPtr(&sw_rightJetBumper));
    if(sw_getState(toSwitchPtr(&sw_leftJetBumper)) == SWITCH_STATE_CLOSED)
        switchOff(toSwitchPtr(&sw_leftJetBumper));
    if(sw_getState(toSwitchPtr(&sw_centerTopRollOver)) == SWITCH_STATE_CLOSED)
        switchOff(toSwitchPtr(&sw_centerTopRollOver));
    if(sw_getState(toSwitchPtr(&sw_rightTopRollOver)) == SWITCH_STATE_CLOSED)
        switchOff(toSwitchPtr(&sw_rightTopRollOver));
    if(sw_getState(toSwitchPtr(&sw_leftTopRollOver)) == SWITCH_STATE_CLOSED)
        switchOff(toSwitchPtr(&sw_leftTopRollOver));
    if(sw_getState(toSwitchPtr(&sw_leftTopTarget)) == SWITCH_STATE_CLOSED)
        switchOff(toSwitchPtr(&sw_leftTopTarget));
    if(sw_getState(toSwitchPtr(&sw_leftBottomRollOverIn)) == SWITCH_STATE_CLOSED)
        switchOff(toSwitchPtr(&sw_leftBottomRollOverIn));
    if(sw_getState(toSwitchPtr(&sw_leftBottomRollOverOut)) == SWITCH_STATE_CLOSED)
        switchOff(toSwitchPtr(&sw_leftBottomRollOverOut));
    if(sw_getState(toSwitchPtr(&sw_leftRightTopRollOverButton)) == SWITCH_STATE_CLOSED)
        switchOff(toSwitchPtr(&sw_leftRightTopRollOverButton));
    if(sw_getState(toSwitchPtr(&sw_centerTopRollOverButton)) == SWITCH_STATE_CLOSED)
        switchOff(toSwitchPtr(&sw_centerTopRollOverButton));
    if(sw_getState(toSwitchPtr(&sw_leftLaneRollOver)) == SWITCH_STATE_CLOSED){
        switchOff(toSwitchPtr(&sw_leftLaneRollOver));
        switchOff(toSwitchPtr(&sw_leftLaneRollOver2));
    }
    if(sw_getState(toSwitchPtr(&sw_spinner)) == SWITCH_STATE_CLOSED)
        switchOff(toSwitchPtr(&sw_spinner));
    }

void sanityCheckGS2(uint8_t event)
{
    if(event != NO_EVENT)
        return;
    if(sw_getState(toSwitchPtr(&sw_shooter)) == SWITCH_STATE_CLOSED)
        switchOff(toSwitchPtr(&sw_shooter));
    if(sw_getState(toSwitchPtr(&sw_outhole)) == SWITCH_STATE_CLOSED)
        switchOff(toSwitchPtr(&sw_outhole));
    if(sw_getState(toSwitchPtr(&sw_creditButton)) == SWITCH_STATE_CLOSED)
        switchOff(toSwitchPtr(&sw_creditButton));
    if(sw_getState(toSwitchPtr(&sw_targetC)) == SWITCH_STATE_CLOSED)
        switchOff(toSwitchPtr(&sw_targetC));
    if(sw_getState(toSwitchPtr(&sw_targetT)) == SWITCH_STATE_CLOSED)
        switchOff(toSwitchPtr(&sw_targetT));
    if(sw_getState(toSwitchPtr(&sw_rightBottomRollOverIn)) == SWITCH_STATE_CLOSED)
        switchOff(toSwitchPtr(&sw_rightBottomRollOverIn));
    if(sw_getState(toSwitchPtr(&sw_rightBottomRollOverOut)) == SWITCH_STATE_CLOSED)
        switchOff(toSwitchPtr(&sw_rightBottomRollOverOut));
}

int main(void)
{
    uint8_t event;
    uint8_t currentEventGS1 = NO_EVENT;
    uint8_t higherPrioEventGS1 = NO_EVENT;
    uint8_t currentEventGS2 = NO_EVENT;
    uint8_t higherPrioEventGS2 = NO_EVENT;

    uint8_t eventRegGS3 = 0x00;
    uint8_t i = 0;
    
    motorFlag = 0;
    
    //disable watchdog
    //MCUCSR = 0;
    wdt_disable();
    
    cli();
    
    // init hardware
    init_hardware();
    
    // Init AZTEC relays
    //init_aztec_relays();
    
    //queue_init(&swInfoQueue, (uint8_t*)switchInfo, sizeof(struct swInfo), SWITCH_INFO_DEPTH);
    
    SPIwrite(0x00);
    while(SPIbusy());
    shiftReg_store(outRegs[0]);
    shiftReg_store(outRegs[1]);
    shiftReg_store(outRegs[2]);
    shiftReg_store(outRegs[3]);
    shiftReg_store(outRegs[4]);
    
    //enable shift register output
    AZTEC_CONTROL_PORT &= ~(1 << AZTEC_OUTPUT_ENABLE);
    
    // globally enable interrupts
    sei();
    
    // Init to game over state
    aztec_init();

    for(;;){
        
        // Event handling for GS1
        if(!isActive(AZTEC_EVENT_SRC_GS1) && currentEventGS1 != NO_EVENT){
            processEvent(AZTEC_EVENT_SRC_GS1, currentEventGS1, 0);
            currentEventGS1 = NO_EVENT;
        }
        if(isActive(AZTEC_EVENT_SRC_GS1) && (AZTEC_INPUT_PIN & 0x0F) != higherPrioEventGS1){
            // End higher prio event
            if(higherPrioEventGS1 != NO_EVENT){
                processEvent(AZTEC_EVENT_SRC_GS1, higherPrioEventGS1, 0);
                higherPrioEventGS1 = NO_EVENT;
            }
            if((AZTEC_INPUT_PIN & 0xF0) != currentEventGS1){
                // Wait a few ms until event becomes stable
                // GSx is slower to decay than the Qxx
                _delay_ms(10);
                // Still active?
                if(isActive(AZTEC_EVENT_SRC_GS1)){
                    // Get event
                    event = (uint8_t)(AZTEC_INPUT_PIN & 0x0F);
                    // Got anything new?
                    if(event > currentEventGS1){
                        higherPrioEventGS1 = event;
                        processEvent(AZTEC_EVENT_SRC_GS1, higherPrioEventGS1, 1);
                        // Else we got a new event
                    } else {
                        currentEventGS1 = event;
                        processEvent(AZTEC_EVENT_SRC_GS1, currentEventGS1, 1);
                    }
                    _delay_ms(25);
                }
            }
        }
        sanityCheckGS1(currentEventGS1);
        
        // Event handling for GS2
        if(!isActive(AZTEC_EVENT_SRC_GS2) && currentEventGS2 != NO_EVENT){
            processEvent(AZTEC_EVENT_SRC_GS2, currentEventGS2, 0);
            currentEventGS2 = NO_EVENT;
        }
        if(isActive(AZTEC_EVENT_SRC_GS2) && (AZTEC_INPUT_PIN & 0xF0) != higherPrioEventGS2){
            // End higher prio event
            if(higherPrioEventGS2 != NO_EVENT){
                processEvent(AZTEC_EVENT_SRC_GS2, higherPrioEventGS2, 0);
                higherPrioEventGS2 = NO_EVENT;
            }
            // Wait a few ms until event becomes stable
            // GSx is slower to decay than the Qxx
            if((AZTEC_INPUT_PIN & 0xF0) != currentEventGS2){
                _delay_ms(10);
                // Still active?
                if(isActive(AZTEC_EVENT_SRC_GS2)){
                    // Get event
                    event = (uint8_t)(AZTEC_INPUT_PIN & 0xF0);
                    // Got anything new?
                    if(event > currentEventGS2){
                        higherPrioEventGS2 = event;
                        processEvent(AZTEC_EVENT_SRC_GS2, higherPrioEventGS2, 1);
                        // Else we got a new event
                    } else {
                        currentEventGS2 = event;
                        processEvent(AZTEC_EVENT_SRC_GS2, currentEventGS2, 1);
                    }
                    _delay_ms(25);
                }
            }
        }
        sanityCheckGS2(currentEventGS2);
        
        // Detect changes on auxiliare inputs (5th IC)
        // NOTE: events can be shadowed by higher priority inputs...
        // Using a state register should help...
        if(isActive(AZTEC_EVENT_SRC_GS3)){
            if(!isBitSet(AZTEC_AUX_INPUT_PIN & AZTEC_AUX_INPUT_MASK, eventRegGS3)){
                _delay_us(200);
                
                // Get current auxiliary event
                event = AZTEC_AUX_INPUT_PIN & AZTEC_AUX_INPUT_MASK;
                
                // End all higher priority events
                for(i = event + 1; i < 8; i++){
                    if(isBitSet(i, eventRegGS3)){
                        clearBit(i, eventRegGS3);
                        processEvent(AZTEC_EVENT_SRC_GS3, i, 0);
                    }
                }
                // Activate current event
                setBit(event, eventRegGS3);
                processEvent(AZTEC_EVENT_SRC_GS3, event, 1);
            }
            // A shadowing event ended?
            if((1 << (AZTEC_AUX_INPUT_PIN & AZTEC_AUX_INPUT_MASK)) < eventRegGS3){
                _delay_us(200);
                event = AZTEC_AUX_INPUT_PIN & AZTEC_AUX_INPUT_MASK;
                for(i = event + 1; i < 8; i++){
                    if(isBitSet(i, eventRegGS3)){
                        clearBit(i, eventRegGS3);
                        processEvent(AZTEC_EVENT_SRC_GS3, i, 0);
                    }
                }
            }
        }
        
        // If there is any auxiliary event flag set but there there is no trigger
        if(eventRegGS3 && !isActive(AZTEC_EVENT_SRC_GS3)){
            // End all active events
            for(i = 0; i < 8; i++){
                if(isBitSet(i, eventRegGS3)){
                    clearBit(i, eventRegGS3);
                    processEvent(AZTEC_EVENT_SRC_GS3, i, 0);
                }
            }
        }

        if(motorFlag){
            motorFlag = 0;
            //_delay_ms(25);
            scoreMotorTurn();
        }

    }
    return 0;   /* never reached */
}

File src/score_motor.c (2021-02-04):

//
//  score_motor.c
//  aztec
//
//  Created by Alexander Warsewa on 21.01.16.
//
//

#include "score_motor.h"
#include "AZTEC_relays.h"
#include "bonus_unit.h"
#include "coin_unit.h"
#include "credit_unit.h"
#include "player_unit.h"

volatile uint8_t motorFlag = 0;

// Motor 'relay'
struct mb1 sw_scoreMotorMotor = { SWITCH_TYPE_MAKE | SWITCH_STATE_OPEN | SWITCH_POWERED, 1, 1, { toSwitchPtr(&scoreMotorTrigger) } };

// CAM Index
// TODO: fill in coin re.
struct mb2 sw_scoreMotorCAM_IndexA = {  SWITCH_TYPE_MAKE | SWITCH_STATE_CLOSED | SWITCH_POWERED, 2, 1,
                                    { toSwitchPtr(&sw_creditButton), toSwitchPtr(&sw_relayCoinE) } };
struct mb2 sw_scoreMotorCAM_IndexB = {  SWITCH_TYPE_MAKE_BREAK | SWITCH_STATE_ALTERNATE | SWITCH_POWERED, 1 | (1 << SWITCH_INDEX_ALTERNATE), 1,
                                        { toSwitchPtr(&sw_relayPlayerResetA), toSwitchPtr(&sw_relayAC) } };
struct mb3 sw_scoreMotorCAM_IndexC = {  SWITCH_TYPE_MAKE_BREAK | SWITCH_STATE_ALTERNATE | SWITCH_POWERED, 1 | (2 << SWITCH_INDEX_ALTERNATE), 1,
                                        { toSwitchPtr(&sw_relayResetA), toSwitchPtr(&sw_shooter), toSwitchPtr(&sw_bonusUnitZeroPos) } };
struct mb2 sw_scoreMotorCAM_IndexD = {  SWITCH_TYPE_MAKE_BREAK | SWITCH_STATE_ALTERNATE | SWITCH_POWERED, 1 | (1 << SWITCH_INDEX_ALTERNATE), 1,
                                        { toSwitchPtr(&(scoreMotor.motor)), toSwitchPtr(&relay_dummy) } };

// CAM1
struct mb1 sw_scoreMotorCAM_1A = { SWITCH_TYPE_MAKE | SWITCH_STATE_OPEN | SWITCH_POWERED, 1, 1, { toSwitchPtr(&sw_relayZC) } };
struct mb2 sw_scoreMotorCAM_1B = { SWITCH_TYPE_MAKE | SWITCH_STATE_OPEN | SWITCH_NOT_POWERED, 2, 0, 
                                 { toSwitchPtr(&relay_dummy), toSwitchPtr(&sw_relayResetF) } };
struct mb4 sw_scoreMotorCAM_1C = { SWITCH_TYPE_MAKE | SWITCH_STATE_OPEN | SWITCH_NOT_POWERED, 4, 0,
                                    {   toSwitchPtr(&sw_playerUnitD), toSwitchPtr(&sw_playerUnitC),
                                        toSwitchPtr(&sw_playerUnitB), toSwitchPtr(&sw_coinUnitWiperD6_1) } };

struct mb1 sw_scoreMotorCAM_1D = { SWITCH_TYPE_MAKE | SWITCH_STATE_OPEN | SWITCH_POWERED, 1, 1, { toSwitchPtr(&sw_relayCenterTargetA) } };
struct mb3 sw_scoreMotorCAM_1E = { SWITCH_TYPE_MAKE_BREAK | SWITCH_STATE_DEFAULT | SWITCH_POWERED, 2 | (1 << SWITCH_INDEX_ALTERNATE), 1, { toSwitchPtr(&relay_dummy), toSwitchPtr(&sw_relayBallIndexE),  toSwitchPtr(&relay_dummy) } };
// CAM2
struct mb1 sw_scoreMotorCAM_2A = { SWITCH_TYPE_MAKE | SWITCH_STATE_OPEN | SWITCH_POWERED, 1, 1, { toSwitchPtr(&sw_relayTC) } };
struct mb1 sw_scoreMotorCAM_2B = { SWITCH_TYPE_MAKE | SWITCH_STATE_OPEN | SWITCH_NOT_POWERED, 1, 0, { toSwitchPtr(&sw_relayPlayerResetC) } };
struct mb1 sw_scoreMotorCAM_2C = { SWITCH_TYPE_MAKE | SWITCH_STATE_OPEN | SWITCH_POWERED, 1, 1, { toSwitchPtr(&relay_dummy) } };
struct mb2 sw_scoreMotorCAM_2D = { SWITCH_TYPE_BREAK | SWITCH_STATE_CLOSED | SWITCH_POWERED, 2, 1,
                                    { toSwitchPtr(&relay_dummy), toSwitchPtr(&relay_dummy) } };

// CAM3
struct mb1 sw_scoreMotorCAM_3A = { SWITCH_TYPE_MAKE | SWITCH_STATE_OPEN | SWITCH_POWERED, 1, 1, { toSwitchPtr(&sw_relayEC) } };
struct mb1 sw_scoreMotorCAM_3B = { SWITCH_TYPE_MAKE | SWITCH_STATE_OPEN | SWITCH_NOT_POWERED, 1, 0, { toSwitchPtr(&relay_bonusUnitStepUp) } };
struct mb1 sw_scoreMotorCAM_3C = { SWITCH_TYPE_MAKE | SWITCH_STATE_OPEN | SWITCH_POWERED, 1, 1, { toSwitchPtr(&sw_coinUnitWiperC8_1) } };
struct mb3 sw_scoreMotorCAM_3D = { SWITCH_TYPE_BREAK | SWITCH_STATE_CLOSED | SWITCH_POWERED, 3, 1,
                                    { toSwitchPtr(&relay_dummy), toSwitchPtr(&sw_scoreMotorCAM_2D), toSwitchPtr(&relay_dummy)} };

// CAM4
struct mb1 sw_scoreMotorCAM_4A = { SWITCH_TYPE_MAKE | SWITCH_STATE_OPEN | SWITCH_POWERED, 1, 1, { toSwitchPtr(&sw_relayCC) } };
struct mb1 sw_scoreMotorCAM_4B = { SWITCH_TYPE_MAKE | SWITCH_STATE_OPEN | SWITCH_NOT_POWERED, 1, 0, { toSwitchPtr(&relay_ballRelease) } };
struct mb1 sw_scoreMotorCAM_4C = { SWITCH_TYPE_MAKE | SWITCH_STATE_OPEN | SWITCH_POWERED, 1, 1, { toSwitchPtr(&sw_coinUnitWiperC8_2) } };
struct mb2 sw_scoreMotorCAM_4D = { SWITCH_TYPE_BREAK | SWITCH_STATE_CLOSED | SWITCH_POWERED, 2, 1,
                                    { toSwitchPtr(&sw_scoreMotorCAM_3D), toSwitchPtr(&relay_dummy) } };
struct mb2 sw_scoreMotorCAM_4E = { SWITCH_TYPE_MAKE_BREAK | SWITCH_STATE_DEFAULT | SWITCH_POWERED, 1 | (1 << SWITCH_INDEX_ALTERNATE), 1,
                                    { toSwitchPtr(&sw_relayBallIndexA), toSwitchPtr(&sw_relayShooterB) } };

// CAM5
struct mb1 sw_scoreMotorCAM_5A = { SWITCH_TYPE_MAKE | SWITCH_STATE_OPEN | SWITCH_POWERED, 1, 1, { toSwitchPtr(&sw_relayDoubleBonusC) } };
struct mb9 sw_scoreMotorCAM_5B = {
    SWITCH_TYPE_MAKE_BREAK | SWITCH_STATE_DEFAULT | SWITCH_POWERED, 8 | (1 << SWITCH_INDEX_ALTERNATE), 1,
    {
        toSwitchPtr(&sw_scoreMotorCAM_4D),
        // TODO: insert remaining 25¢ adj. 
        toSwitchPtr(&relay_dummy),
        toSwitchPtr(&sw_relayCoinA),
        toSwitchPtr(&sw_creditUnitResetEOS),
        toSwitchPtr(&sw_relayShooterA),
        toSwitchPtr(&sw_relayOutholeA),
        toSwitchPtr(&sw_relayCenterTarget2A),
        toSwitchPtr(&sw_relay5000A),
        toSwitchPtr(&sw_coinUnitWiperC8_3)
    }
};

struct mb1 sw_scoreMotorImpulseA = { SWITCH_TYPE_MAKE | SWITCH_STATE_OPEN | SWITCH_NOT_POWERED, 1, 0, { toSwitchPtr(&relay_No123Reset) } };
struct mb1 sw_scoreMotorImpulseB = { SWITCH_TYPE_MAKE | SWITCH_STATE_OPEN | SWITCH_POWERED, 1, 1, { toSwitchPtr(&sw_relayDoubleBonusC2) } };
struct mb5 sw_scoreMotorImpulseC = { SWITCH_TYPE_MAKE | SWITCH_STATE_OPEN | SWITCH_POWERED, 5, 1,
                                    { toSwitchPtr(&relay_dummy), toSwitchPtr(&relay_dummy), toSwitchPtr(&sw_relayBallIndexD),
                                        toSwitchPtr(&sw_relay5000B), toSwitchPtr(&sw_relayAD) } };
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

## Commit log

2021-01-26 added brains schematic
    [AZTEC_motherboard-B.Cu.gbr, AZTEC_motherboard-B.Mask.gbr, AZTEC_motherboard-Edge.Cuts.gbr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]
2021-01-26 added relays board
    [relays_board_v1_0.GBL, relays_board_v1_0.GBO, relays_board_v1_0.GBP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]
2021-02-05 added pcb rendering
2021-02-05 annotated PCB rendering
2021-02-06 added image of schematic symbols
2021-02-07 added image of Z relay
2021-02-10 added score motor image
2021-02-12 added images of relay board
2021-02-12 changed image of relay pcb schematic
2021-02-12 added picture of power supply
2021-02-13 exchanged Eagle PCB with KiCAD version
    [AZTEC_motherboard-B.Cu.gbr, AZTEC_motherboard-B.Mask.gbr, AZTEC_motherboard-Edge.Cuts.gbr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]
2021-02-13 deleted old PCB versions
    [AZTEC_motherboard-B.Cu.gbr, AZTEC_motherboard-B.Mask.gbr, AZTEC_motherboard-Edge.Cuts.gbr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]
